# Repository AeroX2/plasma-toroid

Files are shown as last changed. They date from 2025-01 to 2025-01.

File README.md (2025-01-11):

# Plasma Toroid

This project is a modification of the amazing project that is currently being hosted here
https://hackaday.io/project/194683-plasma-toroid-sky-guided-pcb-edition

# Notable Changes
- Added USB-PD built in
- Removed the arc lighter, since the parts are hard to find and expensive
  - Will probably revisit this in the future
- Trying out two MOSFETs to see heat dissipation, will update the design once I've determined a winner

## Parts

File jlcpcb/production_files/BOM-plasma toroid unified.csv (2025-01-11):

Comment | Designator | Footprint | LCSC
10uF | C10,C2,C4,C5,C9 | C_1206_3216Metric | C13585
0.1uF | C1,C11,C12,C3 | C_0603_1608Metric | C14663
1nF | C13,C7 | C_0603_1608Metric | C1588
10k | R10 | R_1206_3216Metric | C17902
10 | Rg1,Rg2,Rg3,Rg4 | R_2010_5025Metric | C17903
1k | R1,R2 | R_0603_1608Metric | C21190
150 | R3 | R_0603_1608Metric | C22808
2k | R6 | R_0603_1608Metric | C22975
6.8k | R4 | R_0603_1608Metric | C23212
680 | R9 | R_0603_1608Metric | C23228
68k | R5 | R_0603_1608Metric | C23231
47k | R7 | R_0603_1608Metric | C25819
33pf | Cp1,Cp2,Cp3,Cp4 | C_1808_HandSolder | C2915724
1k | R12 | R_1206_3216Metric | C4410
XC6702 | U2 | SOT-89-5
ARC START | SW1 | SW_Push_1P1T_NO_6x6mm_H9.5mm
4.3V | D5 | D_SOD-123
GSD2004S-E3-08 | D4 | SOT-23
IPB17N25S3100ATMA1 | Q2 | TO-263-2_nosilkscreen
47nF | C6 | C_1206_3216Metric
TMP708AIDBVR | U4 | SOT-23-5
6.8k | R8 | R_1206_3216Metric
PA0367A 1:12 | T1 | PA0367A
flash | D2 | LED_1206_3216Metric
IPB17N25S3100ATMA1 | Q1 | TO-263-2_nosilkscreen
LT3402 | U1 | MSOP-10_3x3mm_P0.5mm
6.8nF | C14 | C_1206_3216Metric
HEAT | D7 | LED_1206_3216Metric
15v | D8 | TSOT-23
10k | RV1 | Potentiometer_Bourns_PTV09A-1_Single_Vertical_larger_mount_holes
6.8uH | L1 | L_Bourns_SRR1260_nosilkscreen
470V | GD1 | L_1812_4532Metric
680 | R11 | R_1206_3216Metric
RUN | D6 | LED_1206_3216Metric
MCP1754ST | U3 | SOT-23
PWR | D3 | LED_1206_3216Metric
ZS 1052-S HT(H) | T2 | ZS 1052-S HT(H)
fan header | J2 | PinSocket_1x02_P2.00mm_Vertical
JST-XH | J1 | JST_PH_B2B-PH-K_1x02_P2.00mm_Vertical
Xe Strike | J3 | SolderWire-1sqmm_1x01_D1.4mm_OD2.7mm
1.9uH | L2 | plasmadonut_inductor_2layer_115mm_integrated
Heatsink | HS1 | ATS-18A-05-C2-R0

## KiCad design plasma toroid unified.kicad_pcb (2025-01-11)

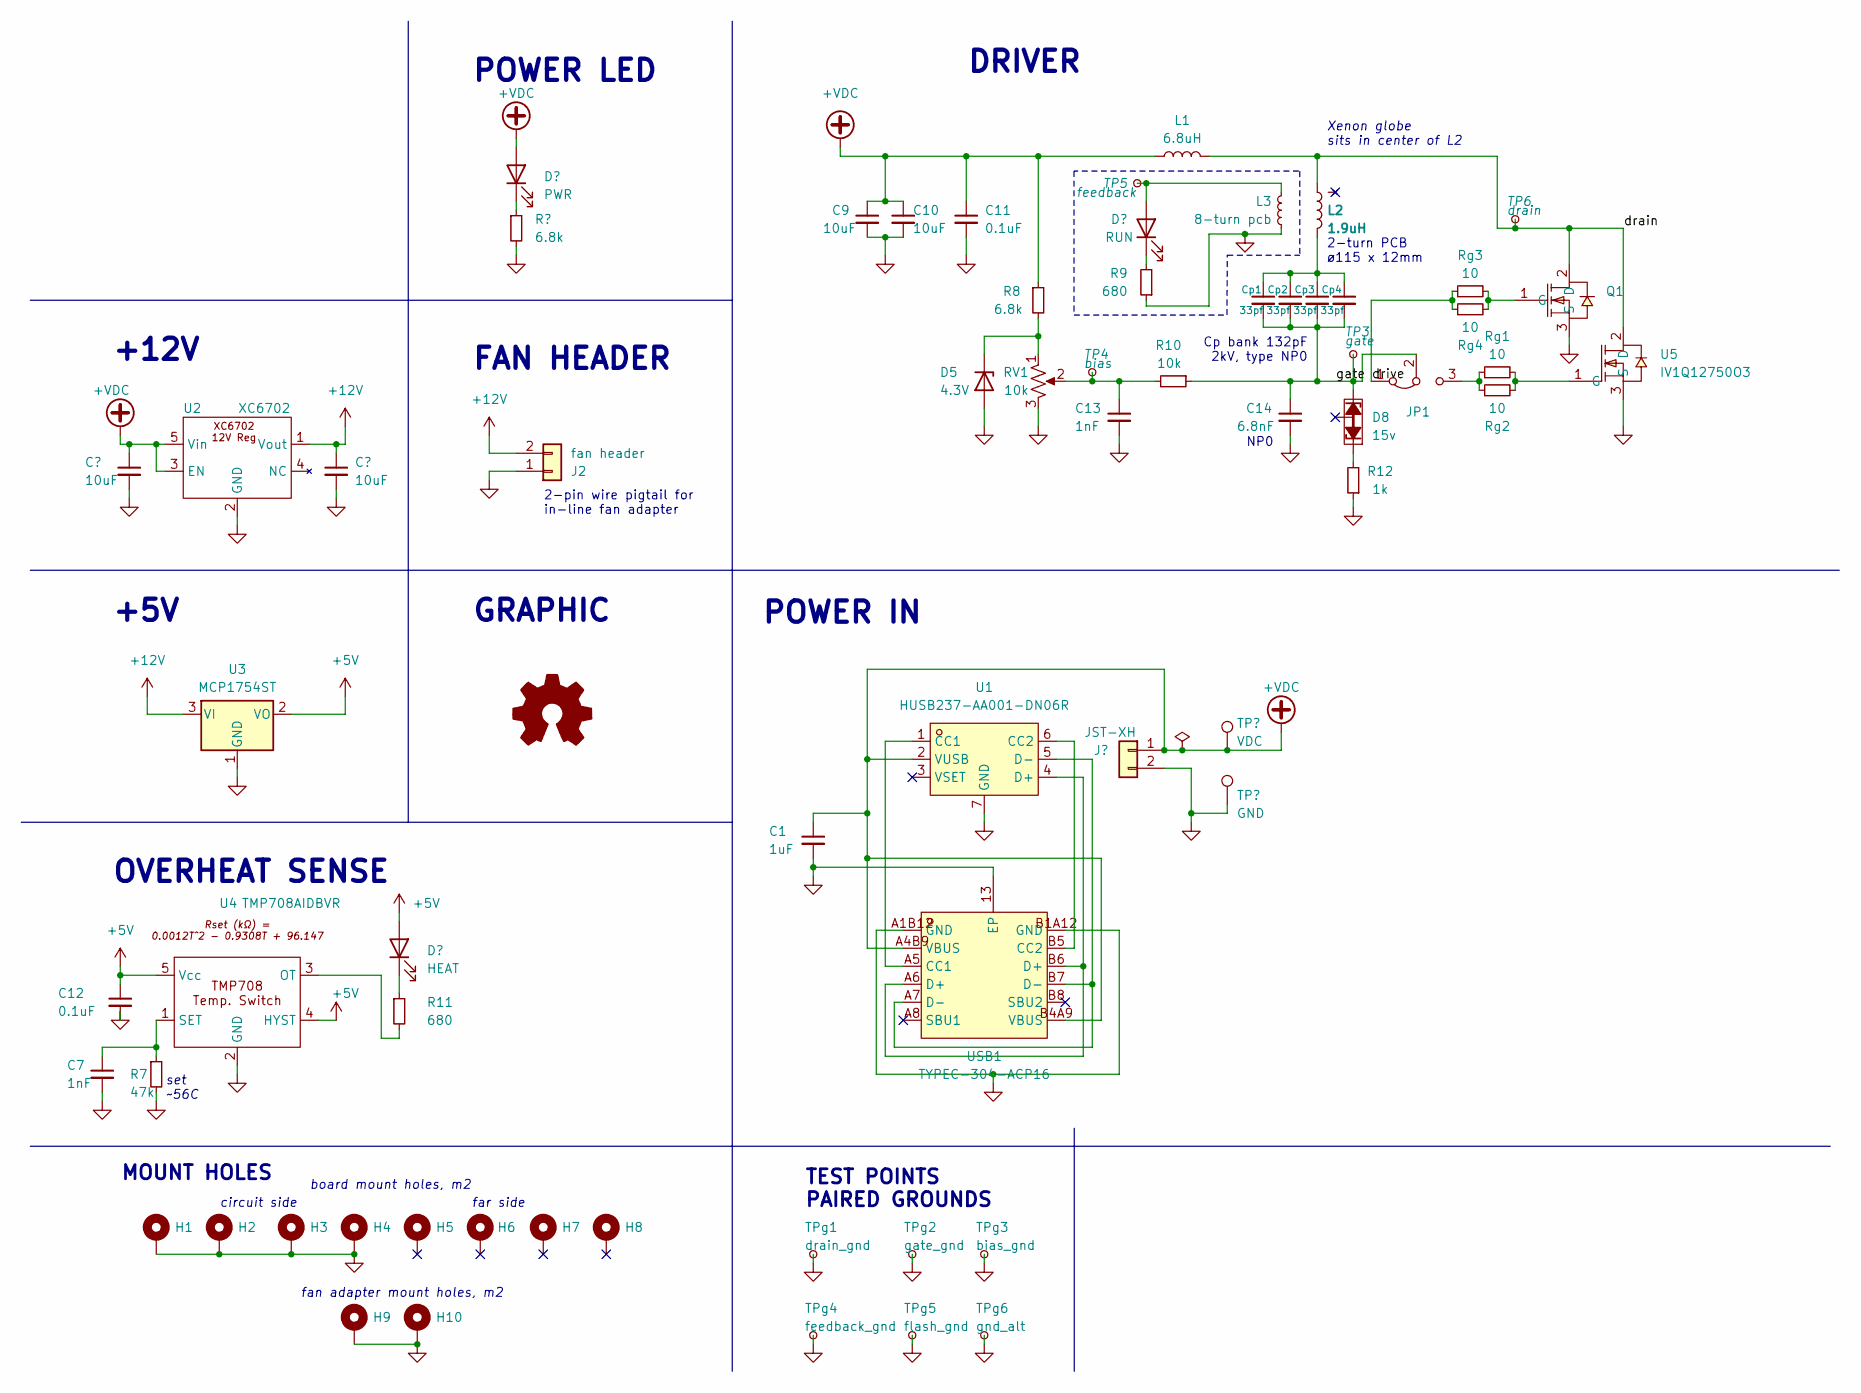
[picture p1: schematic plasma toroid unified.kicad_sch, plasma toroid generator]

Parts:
C1: 1uF; C_0603_1608Metric
C4, C5, C9, C10: 10uF; C_1206_3216Metric
C7, C13: 1nF; C_0603_1608Metric
C11, C12: 0.1uF; C_0603_1608Metric
C14: 6.8nF; C_1206_3216Metric
Cp1, Cp2, Cp3, Cp4: 33pf; C_1808_HandSolder
D3: PWR; LED_1206_3216Metric
D5: 4.3V; D_SOD-123
D6: RUN; LED_1206_3216Metric
D7: HEAT; LED_1206_3216Metric
D8: 15v; TSOT-23
H1, H2, H3, H4, H5, H6, H7, H8, H9, H10: MountingHole; MountingHole_2.2mm_M2_Pad_Via_3.75mmHead
J1: JST-XH; JST_PH_B2B-PH-K_1x02_P2.00mm_Vertical
J2: fan header; PinSocket_1x02_P2.00mm_Vertical
JP1: Jumper_3_Bridged12; SolderJumper-3_P1.3mm_Bridged2Bar12_RoundedPad1.0x1.5mm_Num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
L1: 6.8uH; L_Bourns_SRR1260_nosilkscreen
L2: 1.9uH; plasmadonut_inductor_2layer_115mm_integrated
L3: 8-turn pcb; FEEDBACK_COIL
Q1: NCEP02525F; TO-220F-3_L10.2-W4.7-P2.54-L; LCSC Part C503036
R4: 6.8k; R_0603_1608Metric
R7: 47k; R_0603_1608Metric
R8: 6.8k; R_1206_3216Metric
R9, R11: 680; R_0603_1608Metric
R10: 10k; R_1206_3216Metric
R12: 1k; R_1206_3216Metric
RV1: 10k; Potentiometer_Bourns_PTV09A-1_Single_Vertical_larger_mount_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
Rg1, Rg2, Rg3, Rg4: 10; R_2010_5025Metric
SYM1: Logo_Open_Hardware_Small; OSHW-Symbol_6.7x6mm_Copper
TP1: GND; TestPoint_THTPad_D2.0mm_Drill1.0mm
TP2: VDC; TestPoint_THTPad_D2.0mm_Drill1.0mm
TP3: gate; TestPoint_THTPad_D2.0mm_Drill1.0mm
TP4: bias; TestPoint_THTPad_D2.0mm_Drill1.0mm
TP5: feedback; TestPoint_THTPad_D2.0mm_Drill1.0mm
TP6: drain; TestPoint_THTPad_D2.0mm_Drill1.0mm
TPg1: drain_gnd; TestPoint_THTPad_1.0x1.0mm_Drill0.5mm
TPg2: gate_gnd; TestPoint_THTPad_1.0x1.0mm_Drill0.5mm
TPg3: bias_gnd; TestPoint_THTPad_1.0x1.0mm_Drill0.5mm
TPg4: feedback_gnd; TestPoint_THTPad_1.0x1.0mm_Drill0.5mm
TPg5: flash_gnd; TestPoint_THTPad_1.0x1.0mm_Drill0.5mm
TPg6: gnd_alt; TestPoint_THTPad_D2.5mm_Drill1.2mm
U1: HUSB237-AA001-DN06R; TDFN-6_L2.0-W2.0-P0.65-TL-EP; LCSC Part C22373734
U2: XC6702; SOT-89-5
U3: MCP1754ST; SOT-23
U4: TMP708AIDBVR; SOT-23-5
U5: IV1Q12750O3; TO-220-3_L10.2-W4.5-P2.54-L; LCSC Part C2979250
USB1: TYPEC-304-ACP16; USB-C-SMD_TYPE-C-16P-1; LCSC Part C2982555

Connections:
+5V: C12.1, D7.2 (A), U3.2 (VO), U4.4 (HYST), U4.5 (Vcc)
+12V: C5.1, J2.2, U2.1 (Vout), U3.3 (VI)
+VDC: C1.1, C4.1, C9.1, C10.1, C11.1, D3.2 (A), J1.1, L1.1, R8.1, TP2.1, U1.2 (VUSB), U2.3 (EN), U2.5 (Vin), USB1.A4B9 (VBUS), USB1.B4A9 (VBUS)
/drain: L1.2, L2.2, Q1.2 (D), TP6.1, U5.2 (D)
/gate drive: C14.1, Cp1.2, Cp2.2, Cp3.2, Cp4.2, D8.2 (A), JP1.2 (C), R10.1, TP3.1
GND: C1.2, C4.2, C5.2, C7.2, C9.2, C10.2, C11.2, C12.2, C13.2, C14.2, D5.2 (A), H1.1, H2.1, H3.1, H4.1, H9.1, H10.1, J1.2, J2.1, L3.1, Q1.3 (S), R4.2, R7.2, R9.1, R12.1, RV1.3, TP1.1, TPg1.1, TPg2.1, TPg3.1, TPg4.1, TPg5.1, TPg6.1, U1.7 (GND), U2.2 (GND), U3.1 (GND), U4.2 (GND), U5.3 (S), USB1.13 (EP), USB1.A1B12 (GND), USB1.B1A12 (GND)
unnamed: C13.1, R10.2, RV1.2, TP4.1
unnamed: Cp1.1, Cp2.1, Cp3.1, Cp4.1, L2.1
unnamed: D3.1 (K), R4.1
unnamed: D5.1 (K), R8.2, RV1.1
unnamed: D6.2 (A), L3.2, TP5.1
unnamed: D6.1 (K), R9.2
unnamed: D7.1 (K), R11.1
unnamed: D8.1 (K), R12.2
unnamed: JP1.1 (A), Rg3.1, Rg4.1
unnamed: JP1.3 (B), Rg1.1, Rg2.1
unnamed: Q1.1 (G), Rg3.2, Rg4.2
unnamed: U1.1 (CC1), USB1.A5 (CC1)
unnamed: U1.6 (CC2), USB1.B5 (CC2)
unnamed: U1.4 (D+), USB1.A6 (D+), USB1.B6 (D+)
unnamed: U1.5 (D-), USB1.A7 (D-), USB1.B7 (D-)
unnamed: R11.2, U4.3 (OT)
unnamed: C7.1, R7.1, U4.1 (SET)
unnamed: Rg1.2, Rg2.2, U5.1 (G)

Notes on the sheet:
Xenon globe sits in center of L2
POWER IN
TEST POINTS PAIRED GROUNDS
GRAPHIC
board mount holes, m2
DRIVER
FAN HEADER
POWER LED
fan adapter mount holes, m2
NP0
+12V
2-pin wire pigtail for in-line fan adapter
2-turn PCB ø115 x 12mm
MOUNT HOLES
+5V
circuit side
far side
Cp bank 132pF 2kV, type NP0
set ~56C
OVERHEAT SENSE

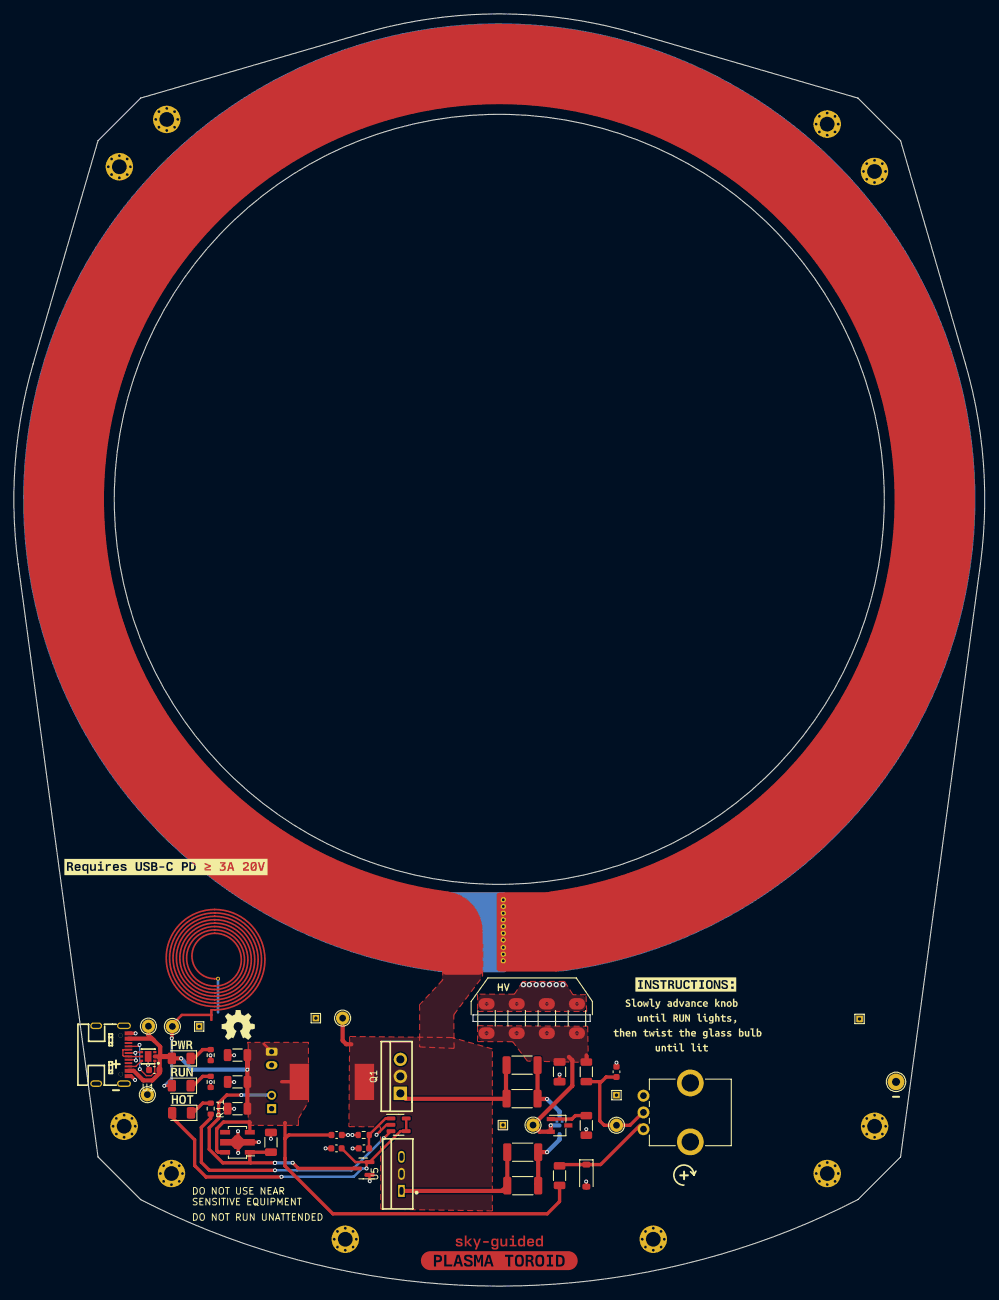
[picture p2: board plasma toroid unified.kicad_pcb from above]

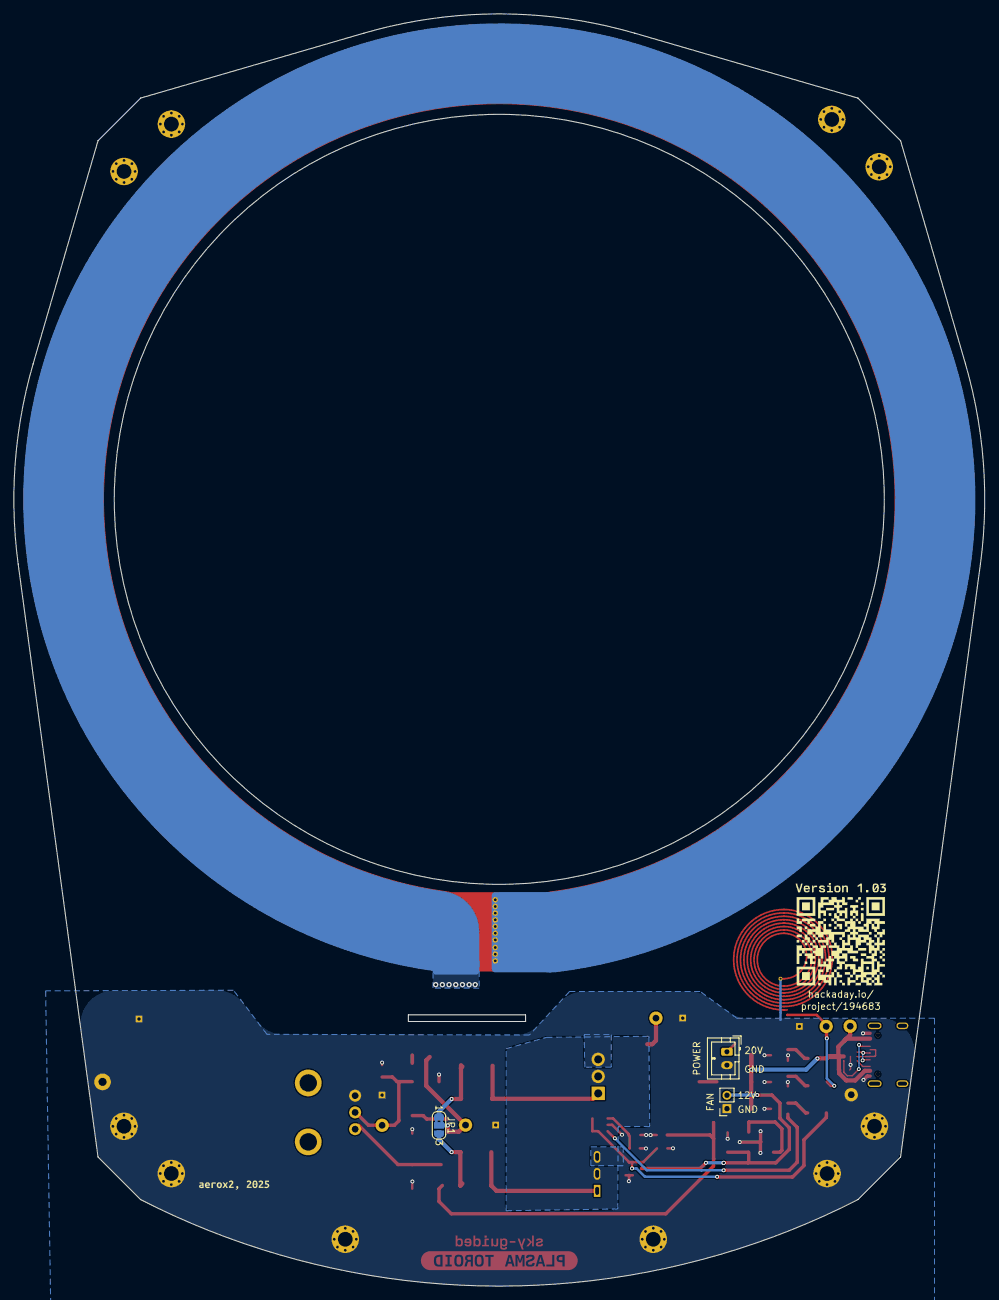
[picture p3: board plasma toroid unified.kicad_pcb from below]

Board: 2 copper layers, 145.0 x 190.0 mm, 78 parts (7 on the bottom side), 24 nets.

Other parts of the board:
QR*****: hackaday.io/; hackadayio qr code
kibuzzard-66C555BE: G***; kibuzzard-66C555BE
kibuzzard-66C556E1: G***; kibuzzard-66C556E1
kibuzzard-66C556ED: G***; kibuzzard-66C556ED
kibuzzard-66EB7AC2: G***; kibuzzard-66EB7AC2
kibuzzard-6619ED63: G***; kibuzzard-6619ED63
kibuzzard-6619ED70: G***; kibuzzard-6619ED70
kibuzzard-6619ED77: G***; kibuzzard-6619ED77
kibuzzard-6637F496: G***; kibuzzard-6637F496
kibuzzard-67825B16: G***; kibuzzard-67825B16
kibuzzard-678256E4: G***; kibuzzard-678256E4
